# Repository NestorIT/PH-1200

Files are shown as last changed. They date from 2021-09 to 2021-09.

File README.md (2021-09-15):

# ON/OFF Automation System for a Uninterruptible Power Supply (UPS): Adding schedule function

This Arduino project was connected to a UPS to power on/off with RTC alarms (its purpose is to extend battery life). In addition, the schedule and shutdown times may also be configured by a HMI via USB port.

## Features
- Isolated voltage sensor.
- Configurable RTC DS3231 alarms (schedule - hour, minute and day of week).
- Audible alarm when UPS inverter is working (main supply has failed).
- Alarm reset button.
- HMI communication via USB port.

## IMPORTANT
**This new version has not been tested yet, however, it was based on a tested and functional one.**

## Credits
DS3231 Arduino library - [jarzebski/Arduino-DS3231](https://github.com/jarzebski/Arduino-DS3231)\
Isolated communication circuit - [pepaslabs/6N137-TTL-Serial-Optoisolator](https://github.com/pepaslabs/6N137-TTL-Serial-Optoisolator)\
Teardrops KiCad script - [NilujePerchut/kicad_scripts](https://github.com/NilujePerchut/kicad_scripts)

## License
This project is licensed under a [GNU General Public License v3.0](https://www.gnu.org/licenses/gpl-3.0.html) by [Engr. Alfredo Morales](https://www.linkedin.com/in/alfredo-morales-0a434a149/).

## Contact
alfredomorales20@gmail.com\
[Linkedin](https://www.linkedin.com/in/alfredo-morales-0a434a149/)

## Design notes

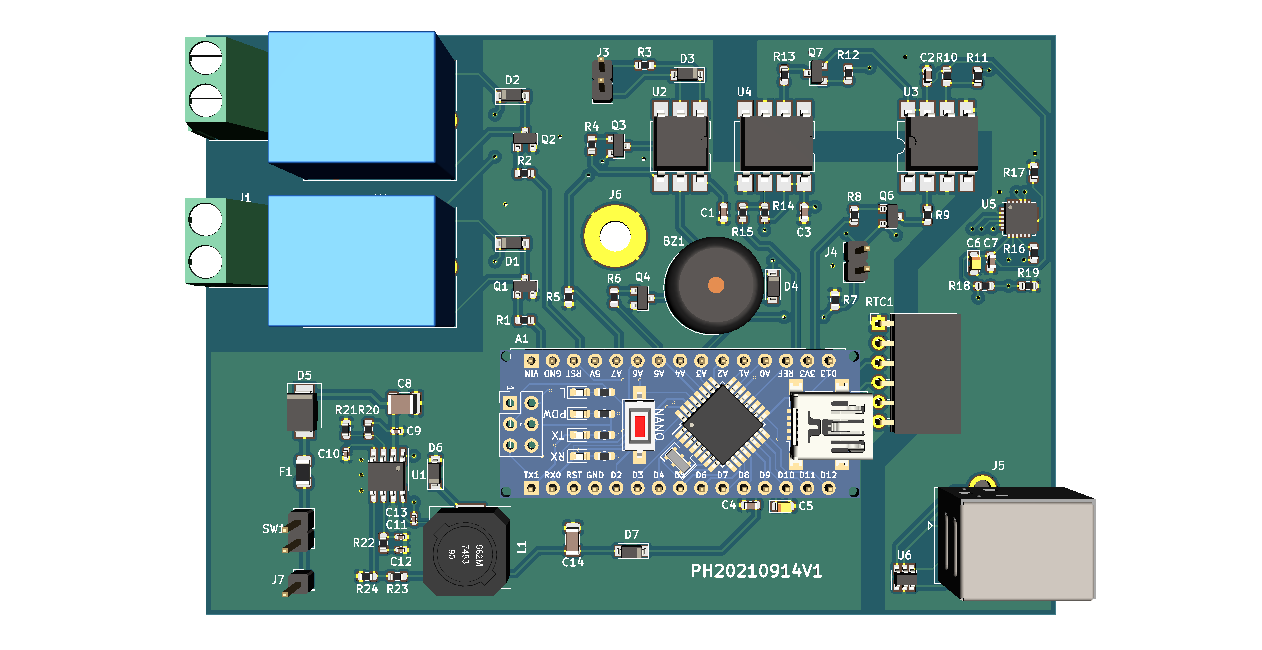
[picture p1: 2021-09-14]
Docs/Images/PH-1200-top.png

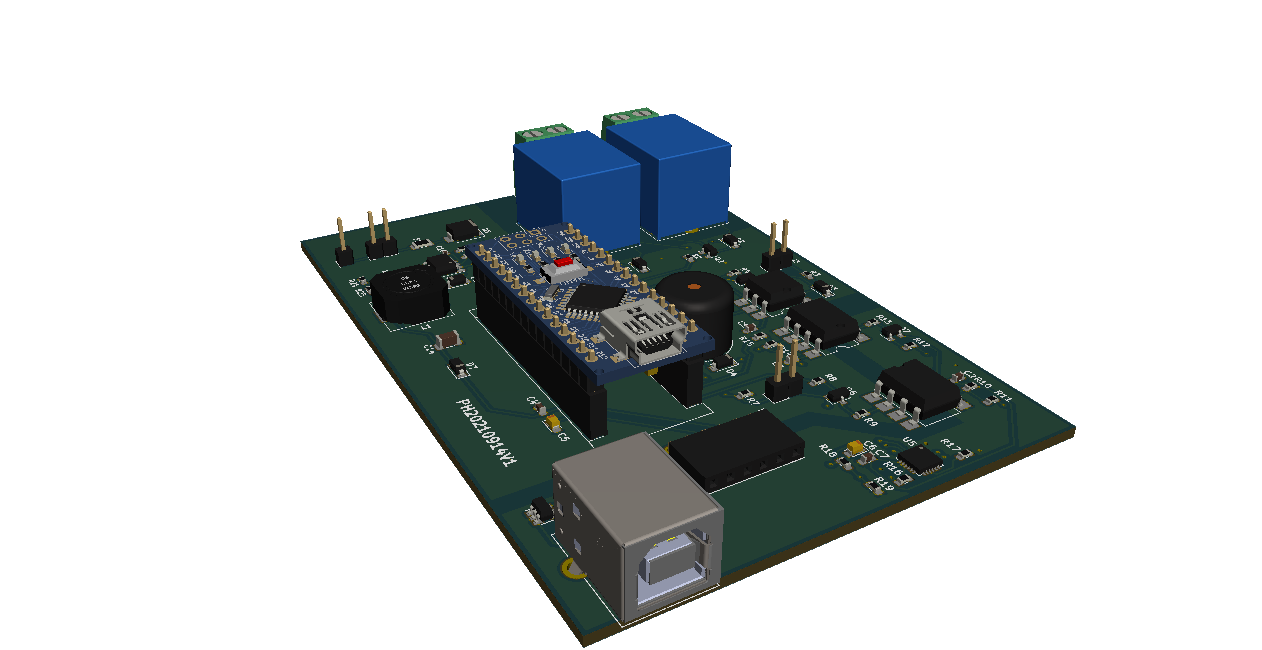
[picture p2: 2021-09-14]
Docs/Images/PH-1200-360-2.png

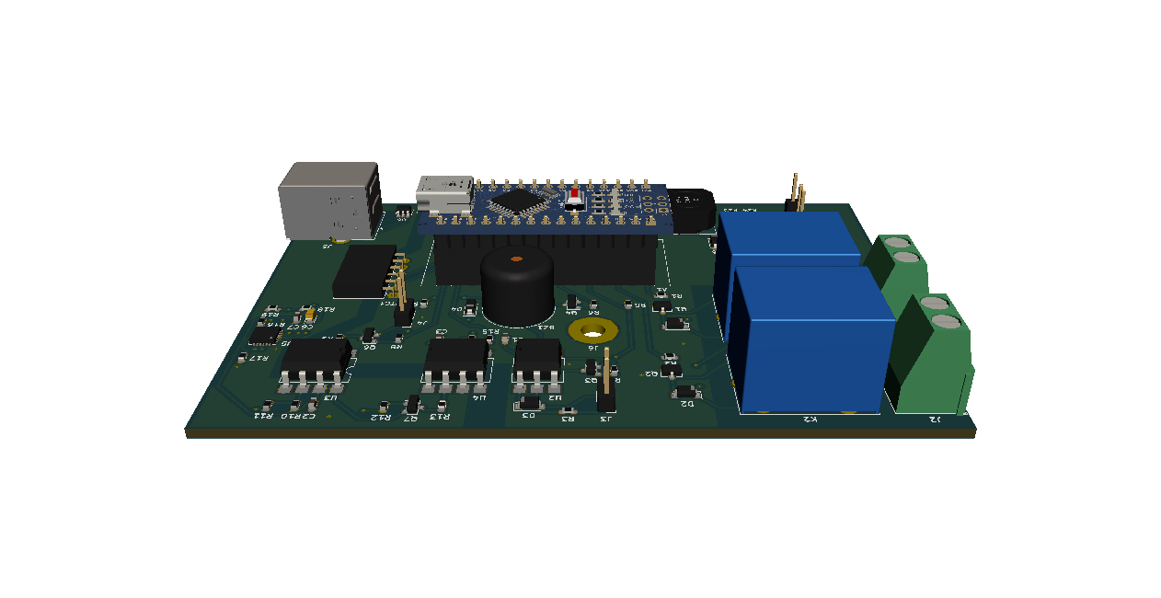
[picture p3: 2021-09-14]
Docs/Images/PH-1200-360-4.png

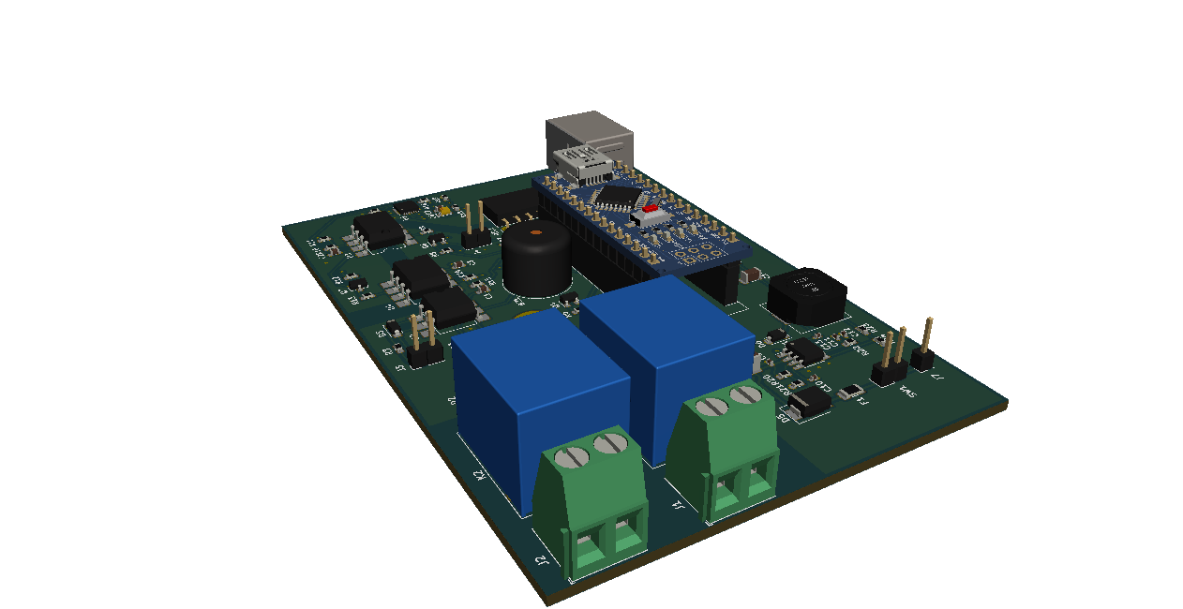
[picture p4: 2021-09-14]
Docs/Images/PH-1200-360-5.png

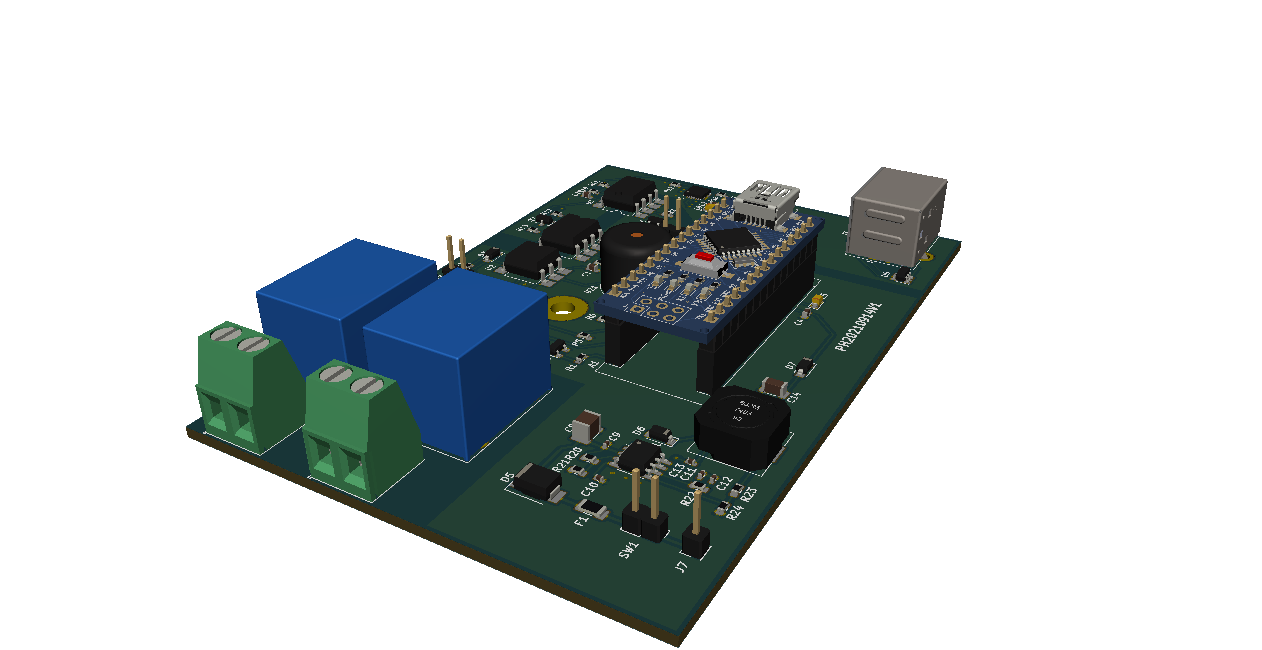
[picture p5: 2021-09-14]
Docs/Images/PH-1200-360-6.png

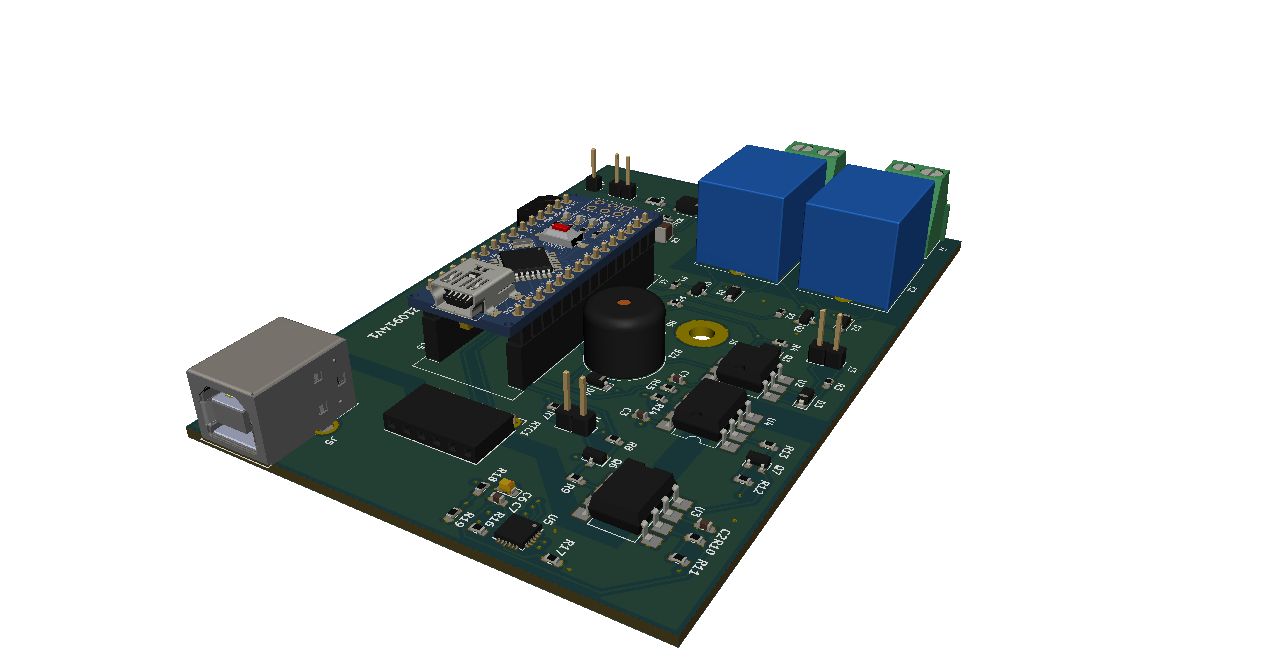
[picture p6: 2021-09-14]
Docs/Images/PH-1200-360-3.png

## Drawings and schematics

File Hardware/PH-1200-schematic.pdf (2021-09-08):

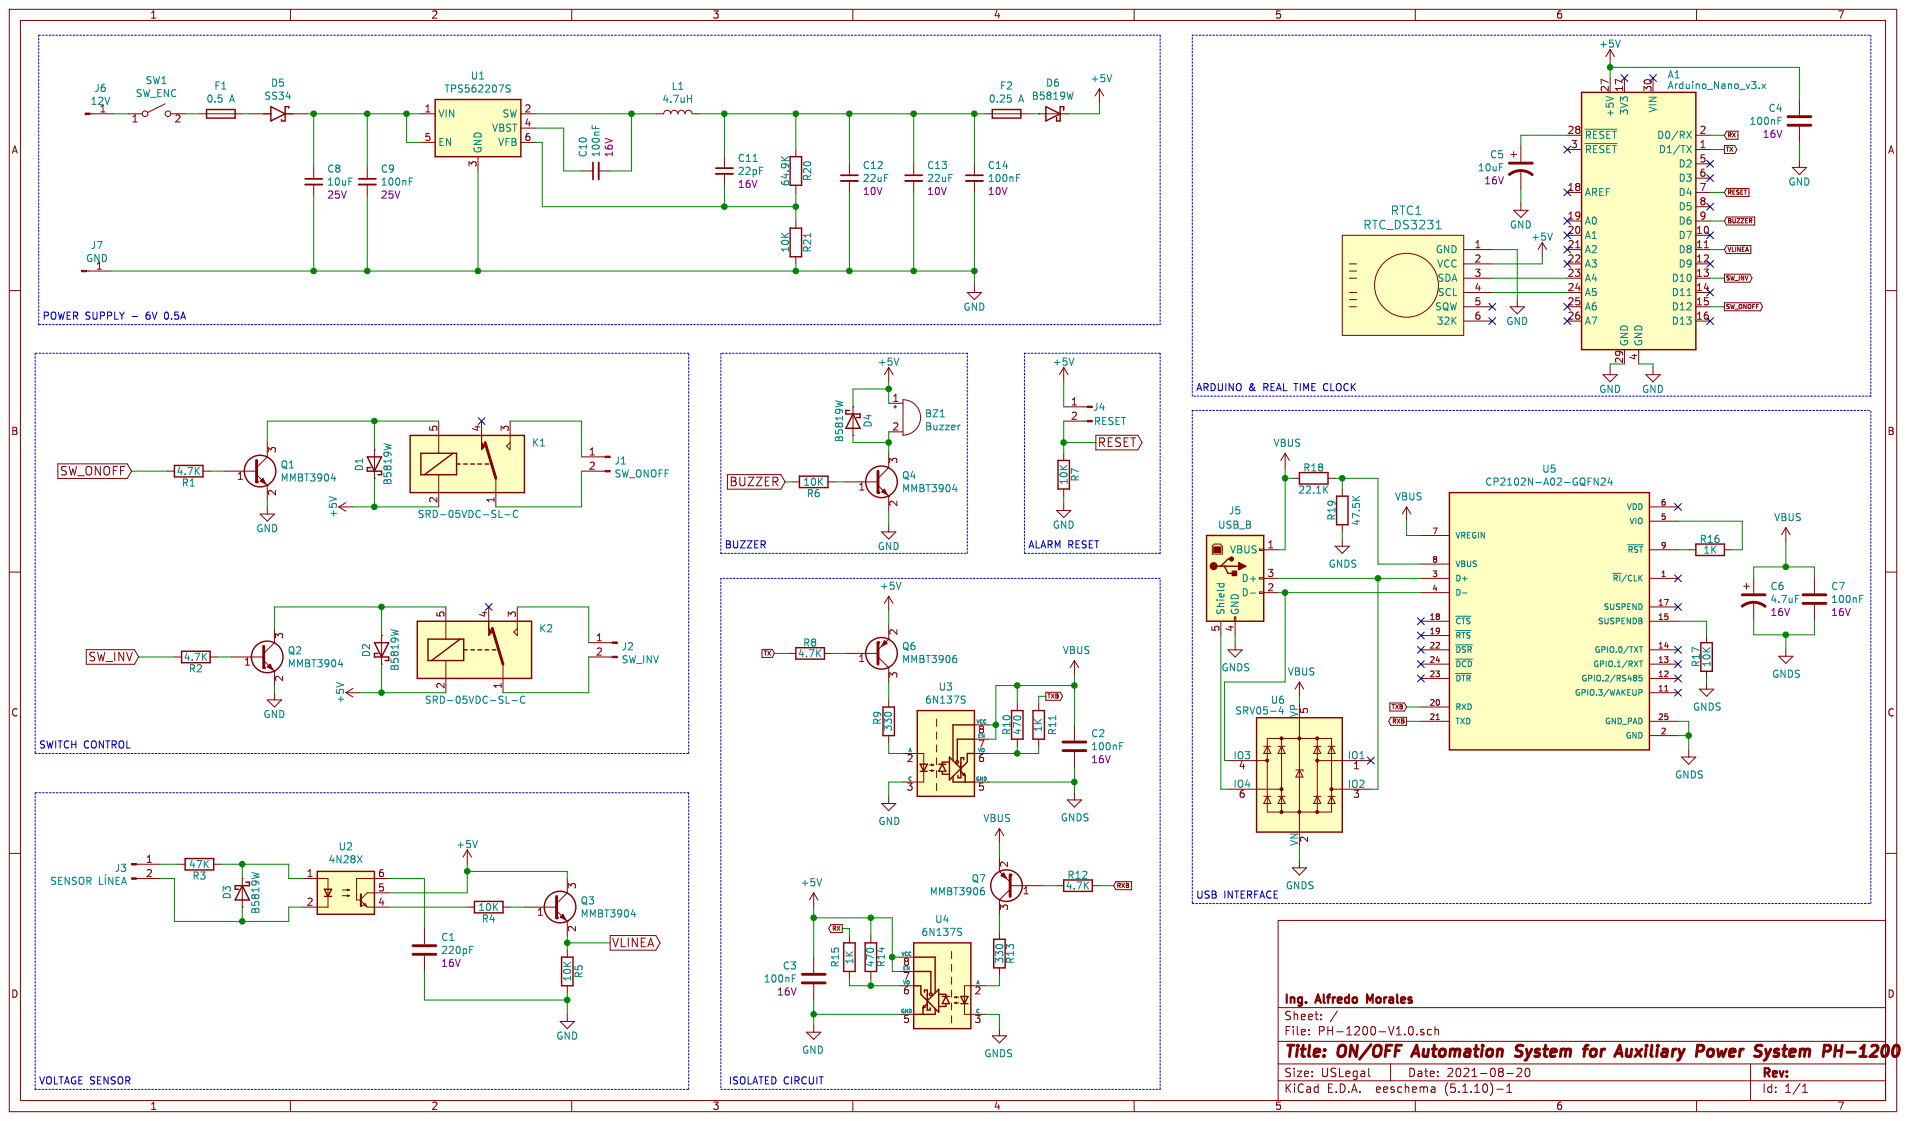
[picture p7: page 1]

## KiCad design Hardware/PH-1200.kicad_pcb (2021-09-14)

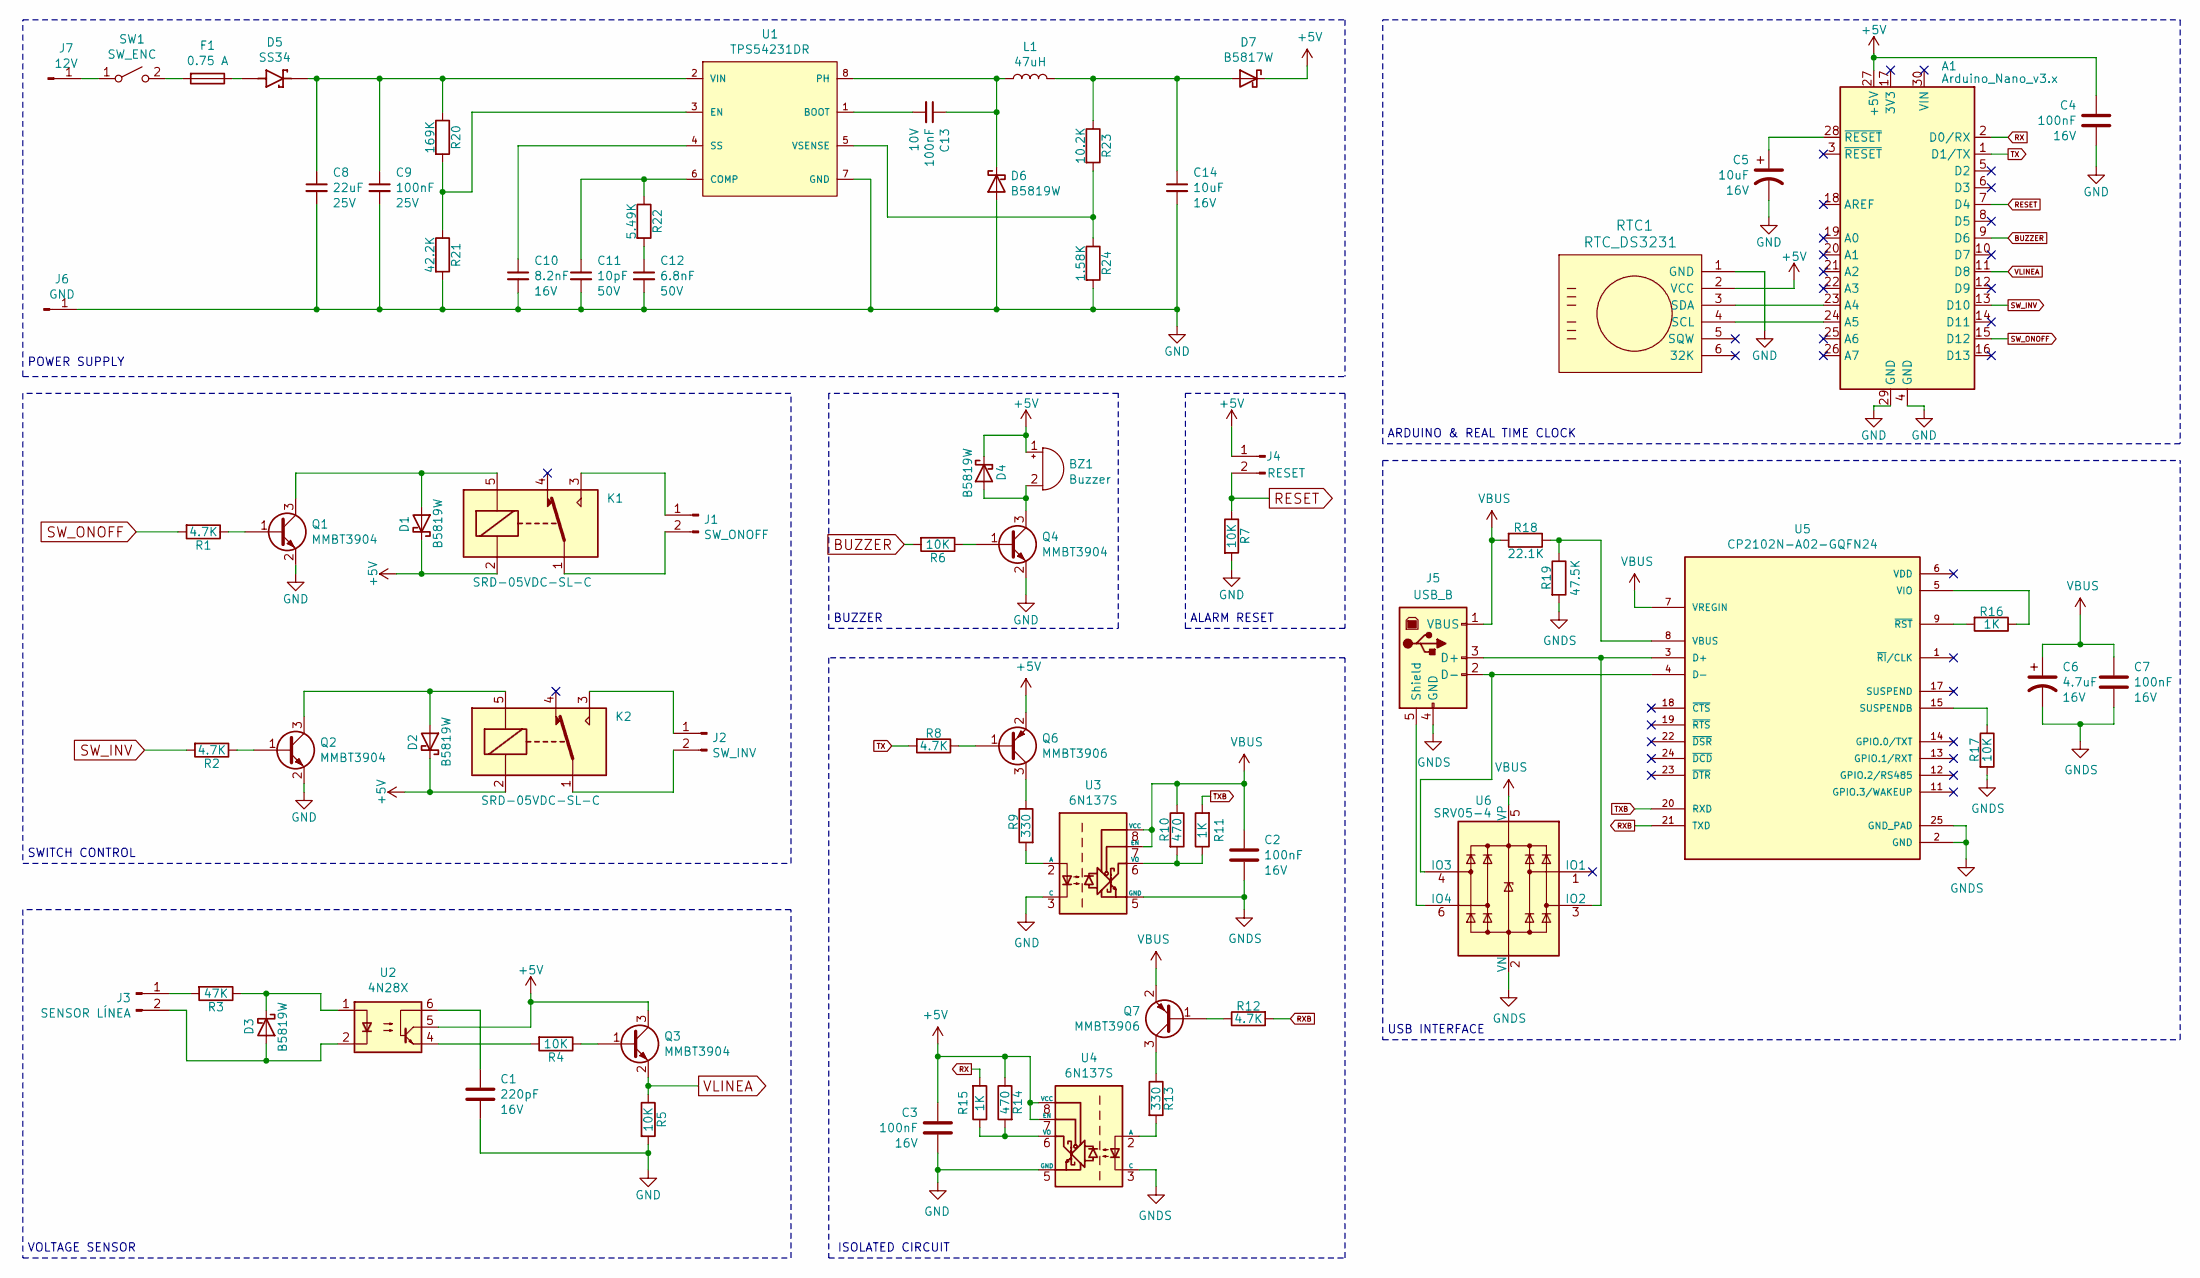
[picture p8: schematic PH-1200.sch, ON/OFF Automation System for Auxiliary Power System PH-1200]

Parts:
A1: Arduino_Nano_v3.x; Arduino_Nano
BZ1: Buzzer; Buzzer_12x9.5RM7.6
C1: 220pF; C_0603_1608Metric; Voltage 16V
C2, C3, C4, C7: 100nF; C_0603_1608Metric; Voltage 16V
C5: 10uF; CP_EIA-2012-12_Kemet-R; Voltage 16V
C6: 4.7uF; CP_EIA-2012-12_Kemet-R; Voltage 16V
C8: 22uF; C_1210_3225Metric; Voltage 25V
C9: 100nF; C_0402_1005Metric; Voltage 25V
C10: 8.2nF; C_0402_1005Metric; Voltage 16V
C11: 10pF; C_0402_1005Metric; Voltage 50V
C12: 6.8nF; C_0402_1005Metric; Voltage 50V
C13: 100nF; C_0402_1005Metric; Voltage 10V
C14: 10uF; C_1206_3216Metric; Voltage 16V
D1, D2, D3, D4, D6: B5819W; D_SOD-123
D5: SS34; D_SMB; PARTREV 31 Aug 2016
D7: B5817W; D_SOD-123
F1: 0.75 A; Fuse_1206_3216Metric; Part C1Q 750
J1: SW_ONOFF; TerminalBlock_Phoenix_MKDS-1,5-2_1x02_P5.00mm_Horizontal
J2: SW_INV; TerminalBlock_Phoenix_MKDS-1,5-2_1x02_P5.00mm_Horizontal
J3: SENSOR LÍNEA; PinHeader_1x02_P2.54mm_Vertical
J4: RESET; PinHeader_1x02_P2.54mm_Vertical
J5: USB_B; USB_B_OST_USB-B1HSxx_Horizontal
J6: GND; MountingHole_4mm_Pad
J7: 12V; PinHeader_1x01_P2.54mm_Vertical
K1, K2: SRD-05VDC-SL-C; Relay_SPDT_SANYOU_SRD_Series_Form_C
L1: 47uH; L_10.4x10.4_H4.8; Part B82464G4473M
Q1, Q2, Q3, Q4: MMBT3904; SOT-23
Q6, Q7: MMBT3906; SOT-23
R1, R2, R8, R12: 4.7K; R_0603_1608Metric
R3: 47K; R_0603_1608Metric
R4, R5, R6, R7, R17: 10K; R_0603_1608Metric
R9, R13: 330; R_0603_1608Metric
R10, R14: 470; R_0603_1608Metric
R11, R15, R16: 1K; R_0603_1608Metric
R18: 22.1K; R_0603_1608Metric
R19: 47.5K; R_0603_1608Metric
R20: 169K; R_0603_1608Metric
R21: 42.2K; R_0603_1608Metric
R22: 5.49K; R_0603_1608Metric
R23: 10.2K; R_0603_1608Metric
R24: 1.58K; R_0603_1608Metric
RTC1: RTC_DS3231; PinSocket_1x06_P2.54mm_Horizontal_Right
SW1: SW_ENC; PinHeader_1x02_P2.54mm_Vertical
U1: TPS54231DR; SOIC-8_3.9x4.9mm_P1.27mm; Rating Catalog
U2: 4N28X; SMDIP-6_W9.53mm
U3, U4: 6N137S; SMDIP-8_W9.53mm
U5: CP2102N-A02-GQFN24; QFN-24-1EP_4x4mm_P0.5mm_EP2.6x2.6mm_ThermalVias; PARTREV 1.3
U6: SRV05-4; SOT-23-6

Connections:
+5V: A1.27 (+5V), BZ1.1 (-), C3.1, C4.1, D1.1 (K), D2.1 (K), D4.1 (K), D7.1 (K), J4.1, K1.2, K2.2, Q3.3 (C), Q6.2 (E), R14.1, RTC1.2 (VCC), U2.5, U4.7 (EN), U4.8 (VCC)
BUZZER: A1.9 (D6), R6.2
GND: A1.4 (GND), A1.29 (GND), C1.2, C3.2, C4.2, C5.2, C8.2, C9.2, C10.2, C11.2, C12.2, C14.2, D6.2 (A), J6.1, Q1.2 (E), Q2.2 (E), Q4.2 (E), R5.2, R7.2, R21.2, R24.2, RTC1.1 (GND), U1.7 (GND), U3.3 (C), U4.5 (GND)
GNDS: C2.2, C6.2, C7.2, J5.4 (GND), R17.2, R19.2, U3.5 (GND), U4.3 (C), U5.2 (GND), U5.25 (GND_PAD), U6.2 (VN)
unnamed: A1.23 (A4), RTC1.3 (SDA)
unnamed: A1.24 (A5), RTC1.4 (SCL)
unnamed: A1.28 (~RESET), C5.1
unnamed: BZ1.2 (+), D4.2 (A), Q4.3 (C)
unnamed: C1.1, U2.6
unnamed: C8.1, C9.1, D5.1 (K), R20.1, U1.2 (VIN)
unnamed: C10.1, U1.4 (SS)
unnamed: C11.1, R22.1, U1.6 (COMP)
unnamed: C12.1, R22.2
unnamed: C13.1, D6.1 (K), L1.1, U1.8 (PH)
unnamed: C13.2, U1.1 (BOOT)
unnamed: C14.1, D7.2 (A), L1.2, R23.1
unnamed: D1.2 (A), K1.5, Q1.3 (C)
unnamed: D2.2 (A), K2.5, Q2.3 (C)
unnamed: D3.1 (K), R3.1, U2.1
unnamed: D3.2 (A), J3.2, U2.2
unnamed: D5.2 (A), F1.1
unnamed: F1.2, SW1.2 (B)
unnamed: J1.1, K1.3
unnamed: J1.2, K1.1
unnamed: J2.1, K2.3
unnamed: J2.2, K2.1
unnamed: J3.1, R3.2
unnamed: J5.2 (D-), U5.4 (D-), U6.4 (IO3)
unnamed: J5.3 (D+), U5.3 (D+), U6.3 (IO2)
unnamed: J5.5 (Shield), U6.6 (IO4)
unnamed: J7.1, SW1.1 (A)
unnamed: Q1.1 (B), R1.1
unnamed: Q2.1 (B), R2.1
unnamed: Q3.1 (B), R4.1
unnamed: Q4.1 (B), R6.1
unnamed: Q6.1 (B), R8.1
unnamed: Q6.3 (C), R9.1
unnamed: Q7.1 (B), R12.1
unnamed: Q7.3 (C), R13.1
unnamed: R4.2, U2.4
unnamed: R9.2, U3.2 (A)
unnamed: R10.2, R11.1, U3.6 (VO)
unnamed: R13.2, U4.2 (A)
unnamed: R14.2, R15.1, U4.6 (VO)
unnamed: R16.1, U5.5 (VIO)
unnamed: R16.2, U5.9 (~RST)
unnamed: R17.1, U5.15 (SUSPENDB)
unnamed: R18.1, R19.1, U5.8 (VBUS)
unnamed: R20.2, R21.1, U1.3 (EN)
unnamed: R23.2, R24.1, U1.5 (VSENSE)
RESET: A1.7 (D4), J4.2, R7.1
RX: A1.2 (D0/RX), R15.2
RXB: R12.2, U5.21 (TXD)
SW_INV: A1.13 (D10), R2.2
SW_ONOFF: A1.15 (D12), R1.2
TX: A1.1 (D1/TX), R8.2
TXB: R11.2, U5.20 (RXD)
VBUS: C2.1, C6.1, C7.1, J5.1 (VBUS), Q7.2 (E), R10.1, R18.2, U3.7 (EN), U3.8 (VCC), U5.7 (VREGIN), U6.5 (VP)
VLINEA: A1.11 (D8), Q3.2 (E), R5.1

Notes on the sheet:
SWITCH CONTROL
VOLTAGE SENSOR
BUZZER
ALARM RESET
ISOLATED CIRCUIT
USB INTERFACE
ARDUINO & REAL TIME CLOCK
POWER SUPPLY

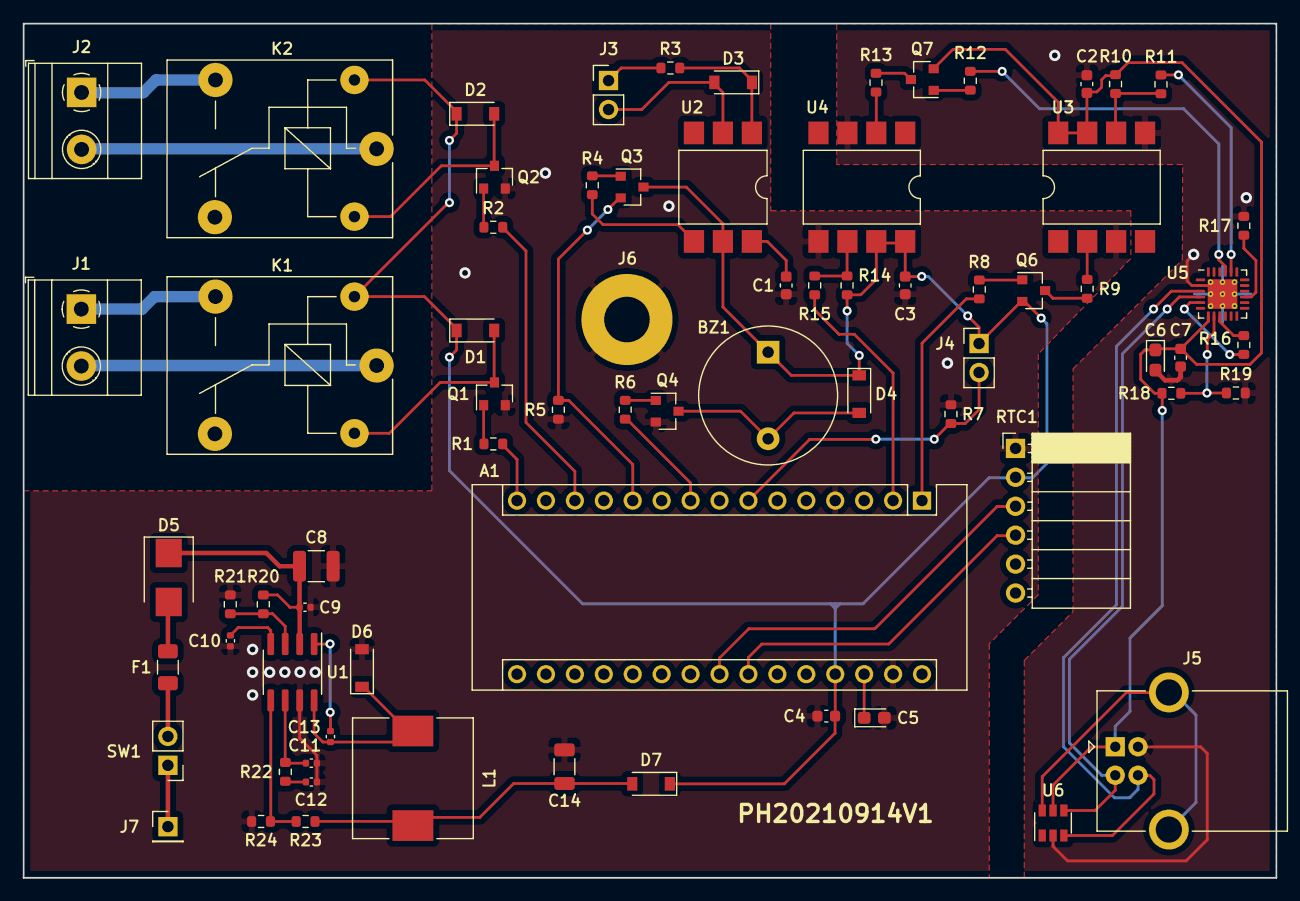
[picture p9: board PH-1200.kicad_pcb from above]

Board: 2 copper layers, 110.0 x 75.0 mm, 72 parts (0 on the bottom side), 59 nets.

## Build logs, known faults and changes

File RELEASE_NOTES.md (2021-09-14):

## PH-1200 1.0 - 2021.09.14

- PCB Untested

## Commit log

2021-09-08 Add KiCad files
    [PH-1200.kicad_pcb, PH-1200.sch]
2021-09-08 Add schematic file
2021-09-08 Add Arduino Nano V3 datasheet
2021-09-14 Update KiCad files
    [PH-1200.kicad_pcb, PH-1200.sch]
2022-12-12 Add RFC 9271
    Add RFC 9271: Uninterruptible Power Supply Management Protocol Commands and Responses
